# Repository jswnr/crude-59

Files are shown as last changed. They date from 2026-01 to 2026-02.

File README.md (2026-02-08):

# Crude-59
A 59-key USB keyboard built using Raspberry Pi Pico

## Images
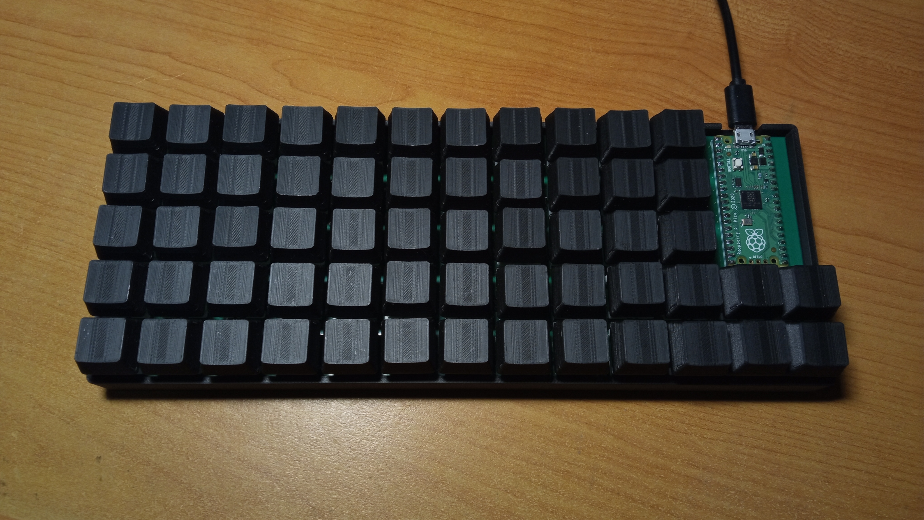
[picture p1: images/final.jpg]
Final

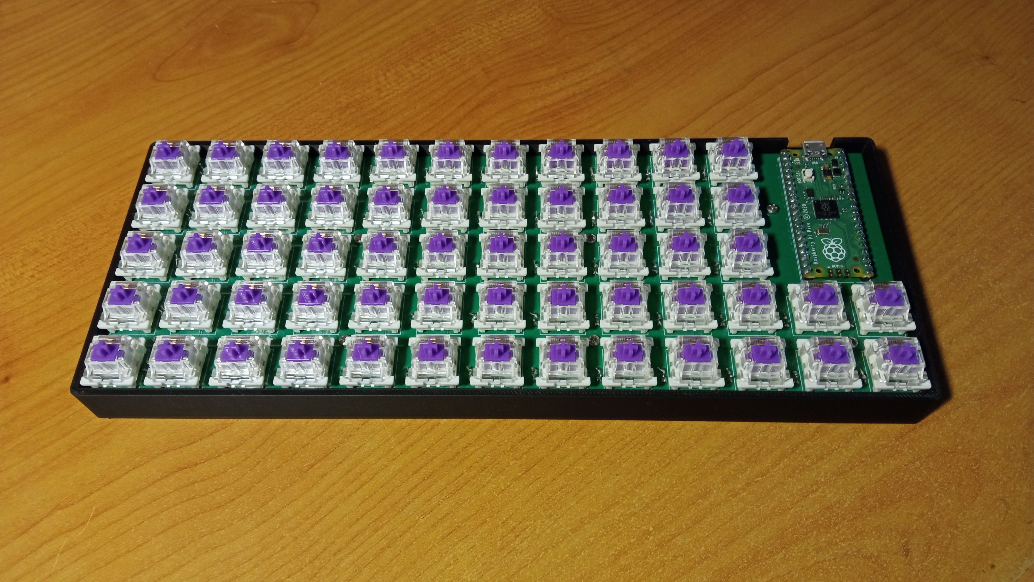
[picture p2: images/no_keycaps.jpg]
No keycaps


## Default layout
| | | | | | | | | | | | | |
|---|---|---|---|---|---|---|---|---|---|---|---|---|
| \`~ | 1! F1 | 2@ F2 | 3# F3 | 4$ F4 | 5% F5 | 6^ F6 | 7& F7 | 8* F8 | 9( F9 | 0) F10 | | |
| Tab | Q | W ↑ | E | R | T | Y | U | I | O | P  F11 | | |
| Esc | A ← | S ↓ | D → | F | G | H | J | K | L | ;: F12 | | | 
| Shift | Z | X | C | V | B | N | M | ,< | .> | '" | Enter | Backspace Delete |
| Control | Super | Fn | Alt | Space | Space | Alt | [{ | ]} | /? | \\\| | -_ | =+ |

## Bill of materials
| Name | Details | Quantity |
|---|---|---|
| 3D printing filament | PLA was used | A/R |
| Solder | | A/R |
| PCB | 1.2 mm thickness | 1 |
| Raspberry Pi Pico | | 1 |
| USB-A to Micro-B cable | | 1 |
| Male pin header | 2.54 mm pitch, 20 pins | 2 |
| M2 screw | Pan head, 6 mm long | 8 |
| M2 brass insert | 6 mm long, 3.5 mm outer diameter | 8 |
| Cherry MX switch | | 59 |
| 1N4148 diode | | 59 |

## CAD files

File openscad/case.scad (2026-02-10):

/*
 * © 2026 Jakub Świniarski
 *
 * SPDX-License-Identifier: CERN-OHL-S-2.0
 */

$fn        = 100;
pcb_t      = 1.2;
insert_d   = 3.5;
thread_l   = 6;
extra_h    = 5;
case_t     = 2.5;
pcb_l      = 244;
pcb_w      = 92;
margin     = 0.5;
rod_hole_r = (insert_d - 0.2) / 2;
rod_h      = thread_l + 2;
rod_r      = rod_hole_r + 2;
rod_thin_r = 1.5;
gusset_l   = 3;
gusset_t   = 1;
wall_l     = 4 + margin;
wall_t     = 1.5;
wall_h_pos = [
    [0, 55.5],
    [pcb_l + (2 * margin) - wall_l, 55.5]
];
wall_v_pos = [
    [46, 0],
    [110, 0],
    [186, 0],
    [84, pcb_w + (2 * margin) - wall_l],
    [148, pcb_w + (2 * margin) - wall_l],
];
rod_pos = [
    [17.5, 17.5],
    [74.5, 17.5],
    [150.5, 17.5],
    [226.5, 17.5],
    [74.5, 55.5],
    [150.5, 55.5],
    [17.5, 74.5],
    [210.5, 67.5]
];
rod_thin_pos = [
    [36.5, 36.5],
    [112.5, 36.5],
    [188.5, 36.5],
    [55.5, 74.5],
    [112.5, 74.5],
    [169.5, 74.5]
];
usb_pos = [226, pcb_w, case_t + rod_h + pcb_t];
usb_size = [15, case_t + 10, extra_h + 10];

module box() {
    minkowski() {
        cube([
            pcb_l + (2 * margin),
            pcb_w + (2 * margin),
            case_t + rod_h + pcb_t + extra_h - 1
        ]);
        cylinder(r = case_t, h = 1);
    }
}

module cavity() {
    translate([0, 0, case_t])
        cube([
            pcb_l + (2 * margin),
            pcb_w + (2 * margin),
            rod_h + extra_h + 10
        ]);
    
    translate([(usb_pos[0] + margin) - (usb_size[0] / 2),
               (usb_pos[1] + margin),
               usb_pos[2]])
        cube(usb_size);
}

module gusset(rod_r, n) {
    triangle = [
        [0, 0],
        [rod_h, 0],
        [0, gusset_l]
    ];

    rotate([0, 0, 45 + (n * 90)])
        union() {
            translate([(gusset_t / 2), rod_r, 0])
                rotate([0, -90, 0])
                    linear_extrude(height = gusset_t)
                        polygon(points = triangle);
            translate([-(gusset_t / 2), 0, 0])
                cube([gusset_t, rod_r, rod_h]);
        }
}

module rod_support(rod_r) {
    for (n = [0:3]) {
        gusset(rod_r, n);
    }
}

module rod(x, y) {
    translate([x, y, case_t])
        difference() {
            union () {
                cylinder(r = rod_r, h = rod_h);
                rod_support(rod_r);
            }
            translate([0, 0, rod_h - rod_h + 0.01])
                cylinder(r = rod_hole_r, h = rod_h);
        }
}

module rod_thin(x, y) {
    translate([x, y, case_t])
        union() {
            cylinder(r = rod_thin_r, h = rod_h);
            rod_support(rod_thin_r);
        }
}

translate([-(pcb_l / 2), -(pcb_w / 2), 0])
    union() {
        difference() {
            box();
            cavity();
        }
        for (w = wall_h_pos) {
            translate([w[0], w[1] + margin, case_t])
                cube([wall_l, wall_t, rod_h]);
        }
        for (w = wall_v_pos) {
            translate([w[0] + margin, w[1], case_t])
                cube([wall_t, wall_l, rod_h]);
        }
        for (r = rod_pos) {
            rod(r[0] + margin, r[1] + margin);
        }
        for (r = rod_thin_pos) {
            rod_thin(r[0] + margin, r[1] + margin);
        }
    }

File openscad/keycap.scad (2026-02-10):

/*
 * © 2026 Jakub Świniarski
 *
 * SPDX-License-Identifier: CERN-OHL-S-2.0
 */

$fn        = 100;
stem_l     = 4;
stem_h     = 3.6;
stem_th    = 1.1;
stem_tv    = 1.3;
extra_h    = 4;
cap_t      = 1.2;
margin     = 0.05;
rod_hole_h = stem_h + 1;
rod_h      = rod_hole_h + extra_h;
rod_r      = (stem_l / 2) + margin + 0.6;
cap_lb     = 18;
cap_lt     = 14;
cavity_lb  = cap_lb - (2 * cap_t);
cavity_lt  = cap_lt - (2 * cap_t);
rib_t      = 0.5;
rib_lb     = cavity_lt + ((extra_h / rod_h) * (cavity_lb - cavity_lt));
curve_h    = 1;
curve_r    = (curve_h + ((cap_lt / 2)^2 / curve_h)) / 2;

module frustum(lb, lt, h) {
    linear_extrude(height = h, scale = lt / lb) {
        square([lb, lb], center = true);
    }
}

module rib() {
    translate([0, (rib_t / 2), extra_h + 0.5])
        rotate([90, 0, 0])
            linear_extrude(height = rib_t)
                polygon(points = [
                    [-(rib_lb / 2), 0],
                    [(rib_lb / 2), 0],
                    [(cavity_lt / 2), extra_h],
                    [-(cavity_lt / 2), extra_h]
                ]);
}

module rod_hole(stem_t) {
    translate([0, 0, (rod_hole_h / 2) - 0.01])
        cube([stem_l + (2 * margin),
              stem_t + (2 * margin),
              rod_hole_h],
              center = true
        );
}

union() {
    difference() {
        difference() {
            minkowski() {
                frustum(cavity_lb, cavity_lt, rod_h + cap_t + curve_h - 1);
                cylinder(r = cap_t, h = 1);
            }
            translate([0, 0, rod_h + cap_t + curve_r])
                rotate([90, 0, 0])
                    cylinder(r = curve_r, h = cap_lb, center = true);
        }
        translate([0, 0, -0.01])
            frustum(cavity_lb, cavity_lt, rod_h);
    }

    difference() {
        union() {
            translate([0, 0, (rod_h / 2)])
                cylinder(r = rod_r, h = rod_h, center = true);
            
            rib();
            rotate([0, 0, 90])
                rib();
        }

        rod_hole(stem_tv);
        rotate([0, 0, 90])
            rod_hole(stem_th);
    }
}

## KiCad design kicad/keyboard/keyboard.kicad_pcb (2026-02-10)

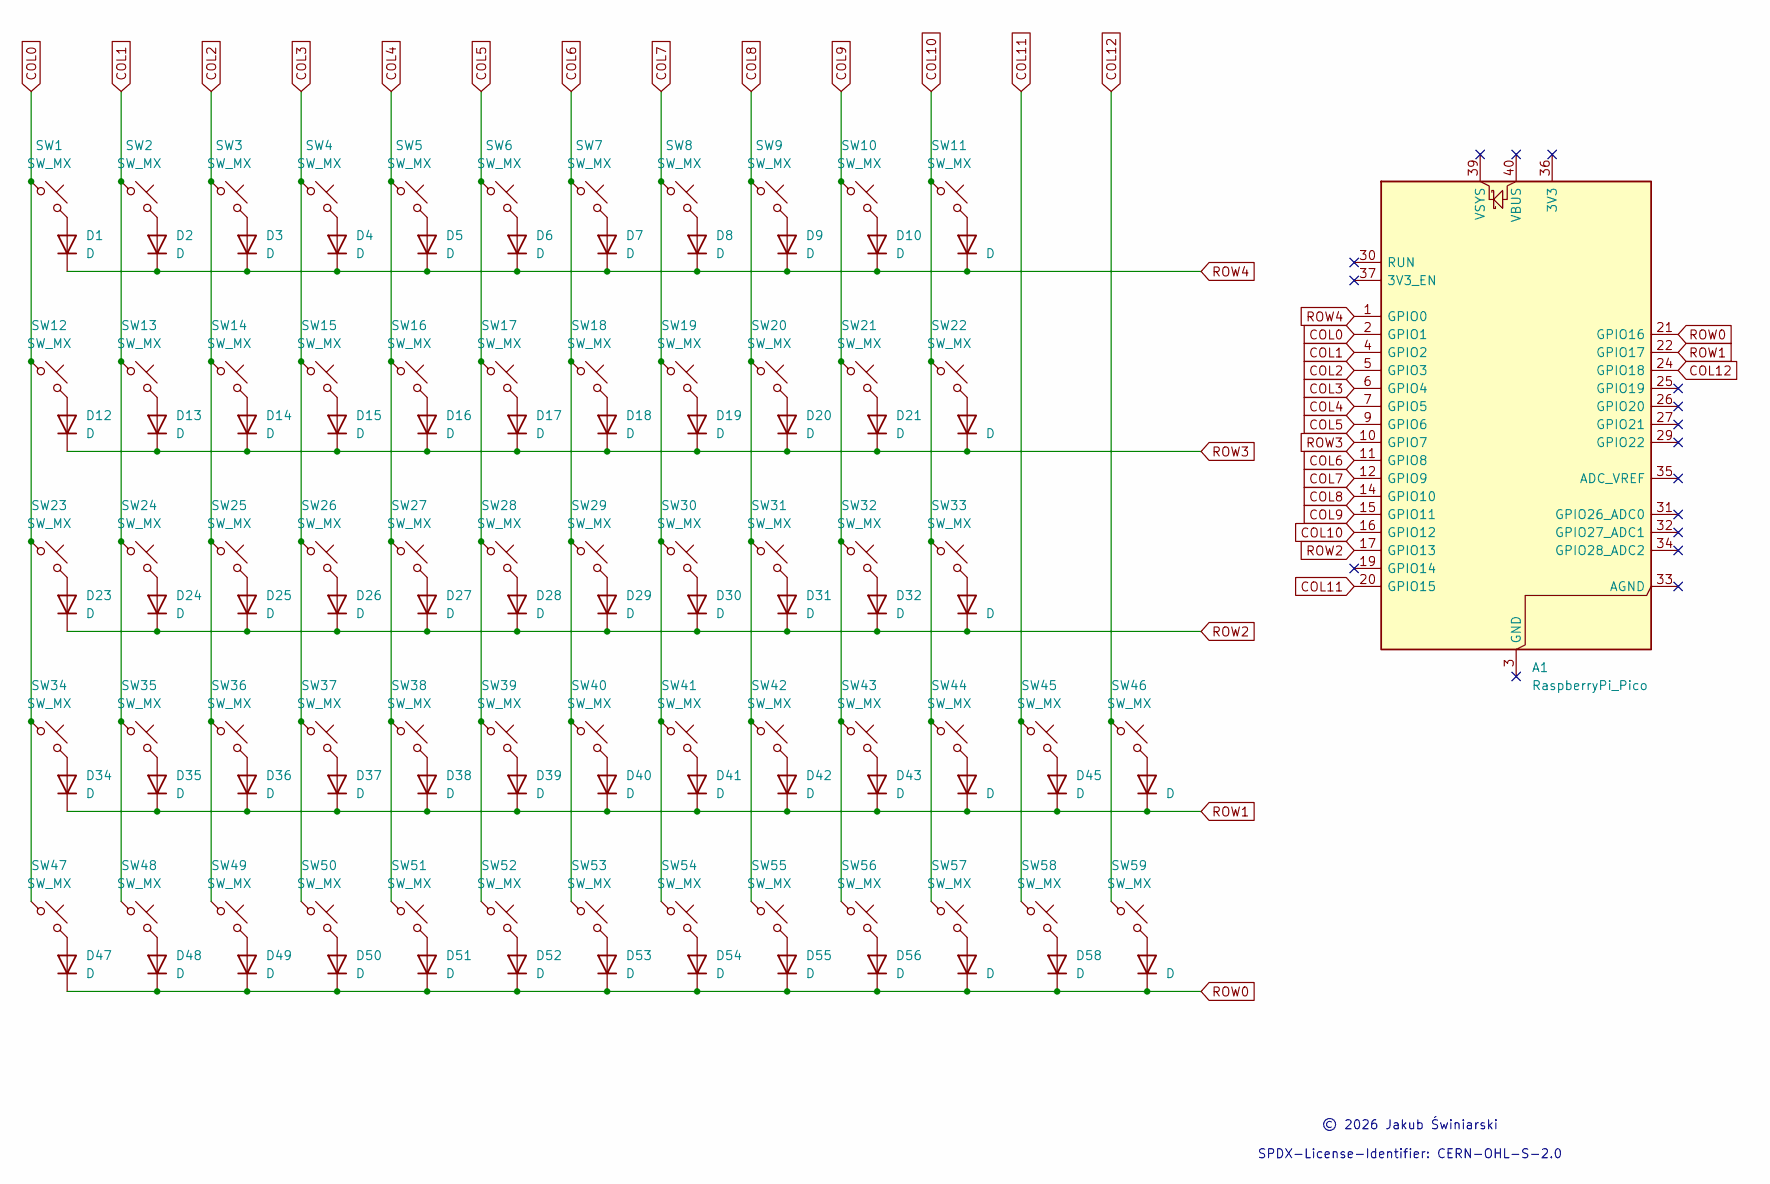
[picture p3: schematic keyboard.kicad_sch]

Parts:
A1: RaspberryPi_Pico; RaspberryPi_Pico_Common_THT
D1, D2, D3, D4, D5, D6, D7, D8, D9, D10, D11, D12, D13, D14, D15, D16, D17, D18, D19, D20, D21, D22, D23, D24, D25, D26, D27, D28, D29, D30, D31, D32, D33, D34, D35, D36, D37, D38, D39, D40, D41, D42, D43, D44, D45, D46, D47, D48, D49, D50, D51, D52, D53, D54, D55, D56, D57, D58, D59: D; D_DO-35_SOD27_P7.62mm_Horizontal
SW1, SW2, SW3, SW4, SW5, SW6, SW7, SW8, SW9, SW10, SW11, SW12, SW13, SW14, SW15, SW16, SW17, SW18, SW19, SW20, SW21, SW22, SW23, SW24, SW25, SW26, SW27, SW28, SW29, SW30, SW31, SW32, SW33, SW34, SW35, SW36, SW37, SW38, SW39, SW40, SW41, SW42, SW43, SW44, SW45, SW46, SW47, SW48, SW49, SW50, SW51, SW52, SW53, SW54, SW55, SW56, SW57, SW58, SW59: SW_MX; SW_Cherry_MX_1.00u_PCB

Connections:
COL0: A1.2 (GPIO1), SW1.1, SW12.1, SW23.1, SW34.1, SW47.1
COL1: A1.4 (GPIO2), SW2.1, SW13.1, SW24.1, SW35.1, SW48.1
COL2: A1.5 (GPIO3), SW3.1, SW14.1, SW25.1, SW36.1, SW49.1
COL3: A1.6 (GPIO4), SW4.1, SW15.1, SW26.1, SW37.1, SW50.1
COL4: A1.7 (GPIO5), SW5.1, SW16.1, SW27.1, SW38.1, SW51.1
COL5: A1.9 (GPIO6), SW6.1, SW17.1, SW28.1, SW39.1, SW52.1
COL6: A1.11 (GPIO8), SW7.1, SW18.1, SW29.1, SW40.1, SW53.1
COL7: A1.12 (GPIO9), SW8.1, SW19.1, SW30.1, SW41.1, SW54.1
COL8: A1.14 (GPIO10), SW9.1, SW20.1, SW31.1, SW42.1, SW55.1
COL9: A1.15 (GPIO11), SW10.1, SW21.1, SW32.1, SW43.1, SW56.1
COL10: A1.16 (GPIO12), SW11.1, SW22.1, SW33.1, SW44.1, SW57.1
COL11: A1.20 (GPIO15), SW45.1, SW58.1
COL12: A1.24 (GPIO18), SW46.1, SW59.1
unnamed: D1.2 (A), SW1.2
unnamed: D2.2 (A), SW2.2
unnamed: D3.2 (A), SW3.2
unnamed: D4.2 (A), SW4.2
unnamed: D5.2 (A), SW5.2
unnamed: D6.2 (A), SW6.2
unnamed: D7.2 (A), SW7.2
unnamed: D8.2 (A), SW8.2
unnamed: D9.2 (A), SW9.2
unnamed: D10.2 (A), SW10.2
unnamed: D11.2 (A), SW11.2
unnamed: D12.2 (A), SW12.2
unnamed: D13.2 (A), SW13.2
unnamed: D14.2 (A), SW14.2
unnamed: D15.2 (A), SW15.2
unnamed: D16.2 (A), SW16.2
unnamed: D17.2 (A), SW17.2
unnamed: D18.2 (A), SW18.2
unnamed: D19.2 (A), SW19.2
unnamed: D20.2 (A), SW20.2
unnamed: D21.2 (A), SW21.2
unnamed: D22.2 (A), SW22.2
unnamed: D23.2 (A), SW23.2
unnamed: D24.2 (A), SW24.2
unnamed: D25.2 (A), SW25.2
unnamed: D26.2 (A), SW26.2
unnamed: D27.2 (A), SW27.2
unnamed: D28.2 (A), SW28.2
unnamed: D29.2 (A), SW29.2
unnamed: D30.2 (A), SW30.2
unnamed: D31.2 (A), SW31.2
unnamed: D32.2 (A), SW32.2
unnamed: D33.2 (A), SW33.2
unnamed: D34.2 (A), SW34.2
unnamed: D35.2 (A), SW35.2
unnamed: D36.2 (A), SW36.2
unnamed: D37.2 (A), SW37.2
unnamed: D38.2 (A), SW38.2
unnamed: D39.2 (A), SW39.2
unnamed: D40.2 (A), SW40.2
unnamed: D41.2 (A), SW41.2
unnamed: D42.2 (A), SW42.2
unnamed: D43.2 (A), SW43.2
unnamed: D44.2 (A), SW44.2
unnamed: D45.2 (A), SW45.2
unnamed: D46.2 (A), SW46.2
unnamed: D47.2 (A), SW47.2
unnamed: D48.2 (A), SW48.2
unnamed: D49.2 (A), SW49.2
unnamed: D50.2 (A), SW50.2
unnamed: D51.2 (A), SW51.2
unnamed: D52.2 (A), SW52.2
unnamed: D53.2 (A), SW53.2
unnamed: D54.2 (A), SW54.2
unnamed: D55.2 (A), SW55.2
unnamed: D56.2 (A), SW56.2
unnamed: D57.2 (A), SW57.2
unnamed: D58.2 (A), SW58.2
unnamed: D59.2 (A), SW59.2
ROW0: A1.21 (GPIO16), D47.1 (K), D48.1 (K), D49.1 (K), D50.1 (K), D51.1 (K), D52.1 (K), D53.1 (K), D54.1 (K), D55.1 (K), D56.1 (K), D57.1 (K), D58.1 (K), D59.1 (K)
ROW1: A1.22 (GPIO17), D34.1 (K), D35.1 (K), D36.1 (K), D37.1 (K), D38.1 (K), D39.1 (K), D40.1 (K), D41.1 (K), D42.1 (K), D43.1 (K), D44.1 (K), D45.1 (K), D46.1 (K)
ROW2: A1.17 (GPIO13), D23.1 (K), D24.1 (K), D25.1 (K), D26.1 (K), D27.1 (K), D28.1 (K), D29.1 (K), D30.1 (K), D31.1 (K), D32.1 (K), D33.1 (K)
ROW3: A1.10 (GPIO7), D12.1 (K), D13.1 (K), D14.1 (K), D15.1 (K), D16.1 (K), D17.1 (K), D18.1 (K), D19.1 (K), D20.1 (K), D21.1 (K), D22.1 (K)
ROW4: A1.1 (GPIO0), D1.1 (K), D2.1 (K), D3.1 (K), D4.1 (K), D5.1 (K), D6.1 (K), D7.1 (K), D8.1 (K), D9.1 (K), D10.1 (K), D11.1 (K)

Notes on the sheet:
© 2026 Jakub Świniarski SPDX-License-Identifier: CERN-OHL-S-2.0

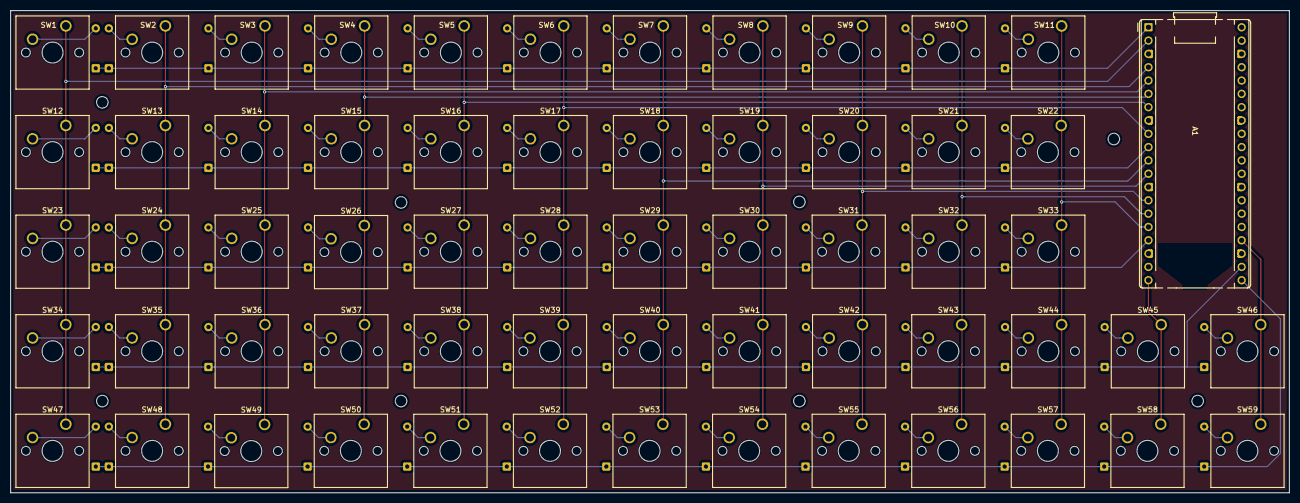
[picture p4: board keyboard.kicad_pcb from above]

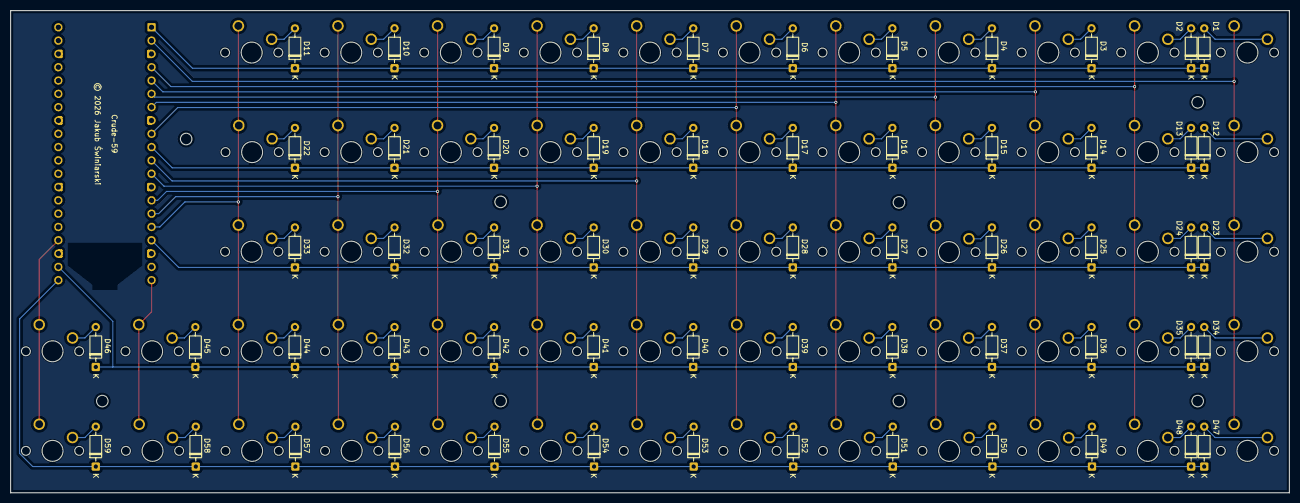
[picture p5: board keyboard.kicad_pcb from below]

Board: 2 copper layers, 244.0 x 92.0 mm, 119 parts (59 on the bottom side), 77 nets.

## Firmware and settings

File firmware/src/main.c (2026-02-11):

/*
 * © 2026 Jakub Świniarski
 *
 * SPDX-License-Identifier: GPL-3.0-or-later
 */

/*
 * The MIT License (MIT)
 *
 * Copyright (c) 2019 Ha Thach (tinyusb.org)
 *
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
 */

#include <bsp/board_api.h>
#include <tusb.h>
#include <hardware/clocks.h>
#include <hardware/structs/clocks.h>

#include "keyboard.h"

void hid_task(void);

uint8_t keycodes[6] = { 0 };

int main(void) {
    board_init();

    set_sys_clock_khz(48000, true);

    clock_stop(clk_adc);
    clock_stop(clk_rtc);
    clock_stop(clk_peri);

    // init device stack on configured roothub port
    tusb_rhport_init_t dev_init = {.role = TUSB_ROLE_DEVICE, .speed = TUSB_SPEED_LOW};
    tusb_init(BOARD_TUD_RHPORT, &dev_init);

    board_init_after_tusb();

    kbd_init();

    while (true) {
        tud_task();
        hid_task();
    }
}

//--------------------------------------------------------------------+
// Device callbacks
//--------------------------------------------------------------------+

// Invoked when device is mounted
void tud_mount_cb(void) {}

// Invoked when device is unmounted
void tud_umount_cb(void) {}

// Invoked when usb bus is suspended
// remote_wakeup_en : if host allow us to perform remote wakeup
// Within 7ms, device must draw an average of current less than 2.5 mA from bus
void tud_suspend_cb(bool remote_wakeup_en) {
    (void)remote_wakeup_en;
    __wfi();
}

// Invoked when usb bus is resumed
void tud_resume_cb(void) {}

//--------------------------------------------------------------------+
// USB HID
//--------------------------------------------------------------------+

static void send_hid_report(bool key_pressed) {
    // skip if hid is not ready yet
    if (!tud_hid_ready()) {
        return;
    }

    // use to avoid send multiple consecutive zero report for keyboard
    static bool send_empty = false;

    if (key_pressed) {
        tud_hid_keyboard_report(1, 0, keycodes);
        send_empty = true;
    } else {
        // send empty key report if previously has key pressed
        if (send_empty) {
            tud_hid_keyboard_report(1, 0, NULL);
        }
        send_empty = false;
    }
}

// tud_hid_report_complete_cb() is used to send the next report after previous one is complete
void hid_task(void) {
    // Poll every 10ms
    const uint32_t  interval_ms = 10;
    static uint32_t start_ms    = 0;

    if (board_millis() - start_ms < interval_ms) {
        return; // not enough time
    }
    start_ms += interval_ms;

    const bool key_pressed = kbd_update(keycodes);

    // Remote wakeup
    if (tud_suspended() && key_pressed) {
        // Wake up host if we are in suspend mode
        // and REMOTE_WAKEUP feature is enabled by host
        tud_remote_wakeup();
    } else {
        // Send the 1st of report chain, the rest will be sent by tud_hid_report_complete_cb()
        send_hid_report(key_pressed);
    }
}

// Invoked when sent REPORT successfully to host
// Application can use this to send the next report
// Note: For composite reports, report[0] is report ID
void tud_hid_report_complete_cb(uint8_t instance, uint8_t const *report, uint16_t len) {
    (void)instance;
    (void)len;
}

// Invoked when received GET_REPORT control request
// Application must fill buffer report's content and return its length.
// Return zero will cause the stack to STALL request
uint16_t tud_hid_get_report_cb(uint8_t instance, uint8_t report_id, hid_report_type_t report_type, uint8_t *buffer, uint16_t reqlen) {
    (void)instance;
    (void)report_id;
    (void)report_type;
    (void)buffer;
    (void)reqlen;

    return 0;
}

// Invoked when received SET_REPORT control request or
// received data on OUT endpoint ( Report ID = 0, Type = 0 )
void tud_hid_set_report_cb(uint8_t instance, uint8_t report_id, hid_report_type_t report_type, uint8_t const *buffer, uint16_t bufsize) {
    (void)instance;
}

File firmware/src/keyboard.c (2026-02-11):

/*
 * © 2026 Jakub Świniarski
 *
 * SPDX-License-Identifier: GPL-3.0-or-later
 */

#include <bsp/board_api.h>
#include <hardware/gpio.h>

#include "layout.h"
#include "keyboard.h"

void kbd_init(void) {
    for (size_t i = 0; i < N_COLS; i++) {
        gpio_init(col_to_gpio[i]);
        gpio_set_dir(col_to_gpio[i], GPIO_IN);
        gpio_pull_up(col_to_gpio[i]);
    }
    
    for (size_t i = 0; i < N_ROWS; i++) {
        gpio_init(row_to_gpio[i]);
        gpio_set_dir(row_to_gpio[i], GPIO_OUT);
        gpio_put(row_to_gpio[i], 1);
    }
}

bool kbd_update(uint8_t *keycodes) {
    for (size_t i = 0; i < 6; i++) {
        keycodes[i] = 0;
    }

    const uint8_t (*cur_layout)[N_ROWS][N_COLS] = &layout;
    gpio_put(row_to_gpio[fn_row], 0);
    sleep_us(5);
    if (gpio_get(col_to_gpio[fn_col]) == 0) {
        cur_layout = &layout_fn;
    }

    uint8_t index = 0;
    bool changed = false;
    for (size_t i = 0; i < N_ROWS; i++) {
        if (index >= 6) {
            break;
        }

        gpio_put(row_to_gpio[i], 0);
        sleep_us(5);

        for (size_t j = 0; j < N_COLS; j++) {
            if (gpio_get(col_to_gpio[j]) != 0)
                continue;

            keycodes[index] = (*cur_layout)[i][j];
            changed = true;
            index++;
            if (index >= 6) {
                break;
            }
        } 

        gpio_put(row_to_gpio[i], 1);
    }

    return changed;
}

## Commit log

2025-12-06 Assign footprints
    [keyboard.kicad_sch]
2025-12-08 Connect rows and columns to Pico
    [keyboard.kicad_pcb, keyboard.kicad_sch]
2025-12-08 Mounting holes and copper fill
    [keyboard.kicad_pcb]
2026-01-19 Add case model
    [case.scad]
2026-01-20 Add more support
    [case.scad]
2026-01-20 USB hole improvements
    [case.scad]
2026-01-20 Configure the model for brass inserts
    [case.scad]
2026-01-22 Minor adjustments
    [case.scad]
2026-01-23 Add gussets
    [case.scad]
2026-01-23 Reduce the size of the rod hole
    [case.scad]
2026-01-24 Update variable names
    [case.scad]
2026-01-24 Add keycap model
    [keycap.scad]
2026-01-25 Add curvature
    [keycap.scad]
2026-01-25 Reduce margin and rod radius, add formula for curve_r
    [keycap.scad]
2026-01-31 Add licenses
    [case.scad, keyboard.kicad_pcb, keyboard.kicad_sch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]
2026-02-01 Add BOM
2026-02-04 Add project name silkscreen and move copyright silkscreen
    [keyboard.kicad_pcb]
2026-02-08 Add pin headers to BOM
2026-02-10 Update copyright notices
    [case.scad, keyboard.kicad_pcb, keyboard.kicad_sch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]
